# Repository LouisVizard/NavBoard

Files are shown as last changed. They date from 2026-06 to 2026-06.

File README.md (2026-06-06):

<div align="center">

# 🛰️ Navigation Board PCB

**A compact, 6-layer embedded navigation platform for real-time sensor fusion and wireless telemetry**







</div>

---

## 📌 Overview

The **Navigation Board** is a custom PCB designed as a dedicated navigation and state estimation platform. It integrates GNSS positioning, inertial sensing, and wireless communication onto a single, compact board — enabling real-time vehicle attitude estimation via a Kalman filter and live data streaming to a host computer for visualization.

> The hardware is complete and functional. Active development is now focused on firmware (EKF implementation) and the host-side Python visualization pipeline.

---

## 🖼️ Board Preview

| Isometric Top | Isometric Bottom |
|:---:|:---:|
| 3D Render Top | 3D Render Bottom |

<details>
<summary>📐 PCB Layout</summary>
<br>

PCB Layout

</details>

<details>
<summary>🔌 Full Schematic</summary>
<br>

Schematic

</details>

---

## ⚡ Specifications

| Parameter | Value |
|---|---|
| **MCU** | STM32F4CEU6 |
| **GNSS Receiver** | u-blox NEO-M9N |
| **IMU** | 9DOF — Accelerometer + Gyroscope + Magnetometer |
| **Wireless** | nRF24L01 (2.4 GHz RF) |
| **Power Input** | Single-cell LiPo + USB-C charging |
| **PCB Stackup** | 6-layer, impedance controlled |

---

## 🏗️ System Architecture

```
┌─────────────┐     ┌─────────────────────────┐     ┌──────────────────┐     ┌──────────────────┐
│  GNSS       │     │                         │     │                  │     │                  │
│  NEO-M9N    │────▶│     STM32F4CEU6         │────▶│  nRF24L01        │────▶│  Host PC         │
│  (UART)     │     │   Kalman Filter /        │     │  2.4 GHz RF Link │     │  Python Viz      │
├─────────────┤     │   Sensor Fusion          │     │                  │     │                  │
│  IMU 9DOF   │     │                         │     │                  │     │                  │
│  (SPI/I2C)  │────▶│                         │     │                  │     │                  │
└─────────────┘     └─────────────────────────┘     └──────────────────┘     └──────────────────┘
```

**Goal:** Fuse absolute positioning (GNSS) with high-rate inertial data (IMU) using an Extended Kalman Filter to estimate real-time orientation and motion, then stream state estimates wirelessly to a host computer for visualization.

---

## 🔧 Design Details

### Hardware Integration

The board centers around the **STM32F4** MCU, which interfaces with:
- **NEO-M9N** GNSS receiver over **UART** for global positioning
- **9DOF IMU** over **SPI/I2C** for high-rate motion sensing
- **nRF24L01** providing a low-latency **2.4 GHz RF link** to stream processed state estimates to an external computer

### Power System

Powered by a single-cell **LiPo battery** with onboard **USB-C charging** circuitry. Independent regulation stages supply stable rails for:
- RF front-end
- Digital logic
- Analog sensing paths

This architecture minimizes noise coupling into sensitive IMU measurements.

### PCB Stackup

A **6-layer stackup** was chosen to provide:
- Controlled impedance for RF and GNSS antenna traces
- Solid ground referencing across all layers
- Clean power distribution

Dedicated power and ground planes minimize EMI and improve signal integrity throughout.

---

## 📊 PCB Stackup Details

The full layer stackup with impedance targets and material specifications is documented in the design spreadsheet:

📄 **[View Stackup Spreadsheet (Google Sheets)](https://docs.google.com/spreadsheets/d/1y8UFBo5hvFj5DNxBOYgQXF0sVpvpMorS/preview)**

---

## 🗺️ Roadmap

The hardware platform is complete. Next steps are focused on firmware and software:

- [ ] Implement **Extended Kalman Filter (EKF)** for GNSS + IMU fusion on STM32F4
- [ ] Tune process and measurement noise covariance matrices
- [ ] Stream state estimates over nRF24L01 RF link
- [ ] Develop **Python visualization** for real-time attitude display
- [ ] Validate filter output against ground truth measurements

---

## 🛠️ Tech Stack

| Layer | Technology |
|---|---|
| **Hardware Design** | KiCad |
| **Firmware** | C (STM32 HAL / bare-metal) |
| **Host Software** | Python |
| **Comms Protocol** | nRF24L01 2.4 GHz |

---

## 👤 Author

**Luis Martinez**





---

<div align="center">
<sub>Built with KiCad · STM32 · u-blox · nRF24L01</sub>
</div>

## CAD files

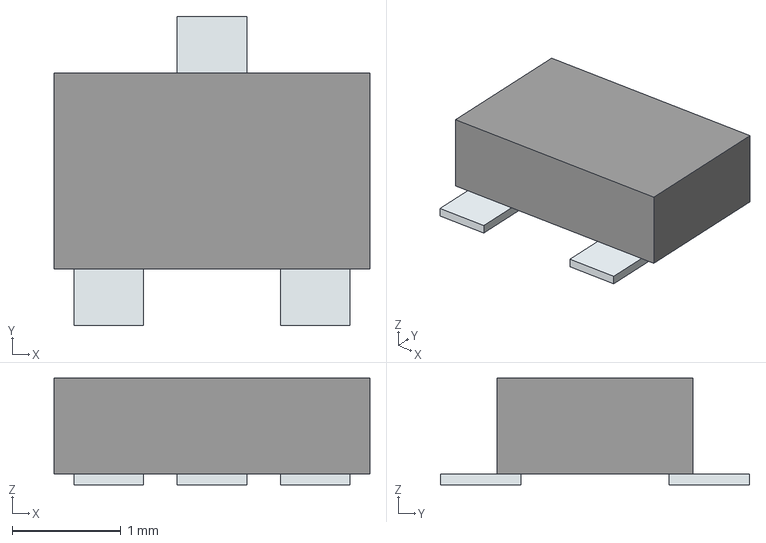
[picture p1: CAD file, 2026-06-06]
3D_Models/SSM3J372R,LF.stp
2.90 x 2.84 x 0.98 mm
Pins

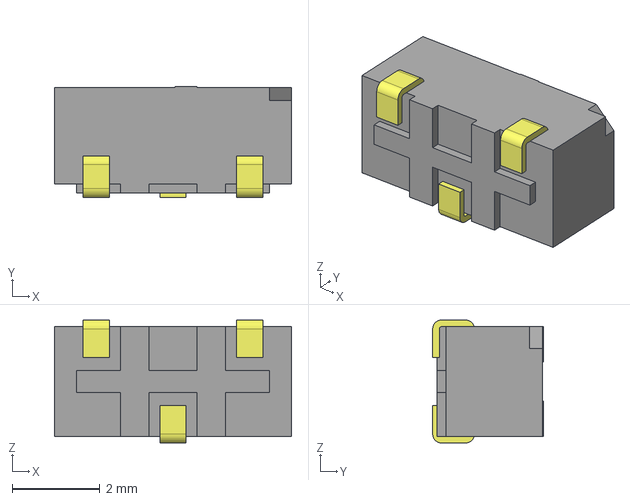
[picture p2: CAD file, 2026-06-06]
3D_Models/CJS-1200TA2.stp
5.40 x 2.52 x 2.80 mm
_CJS_c_11
_CJS Slider_s

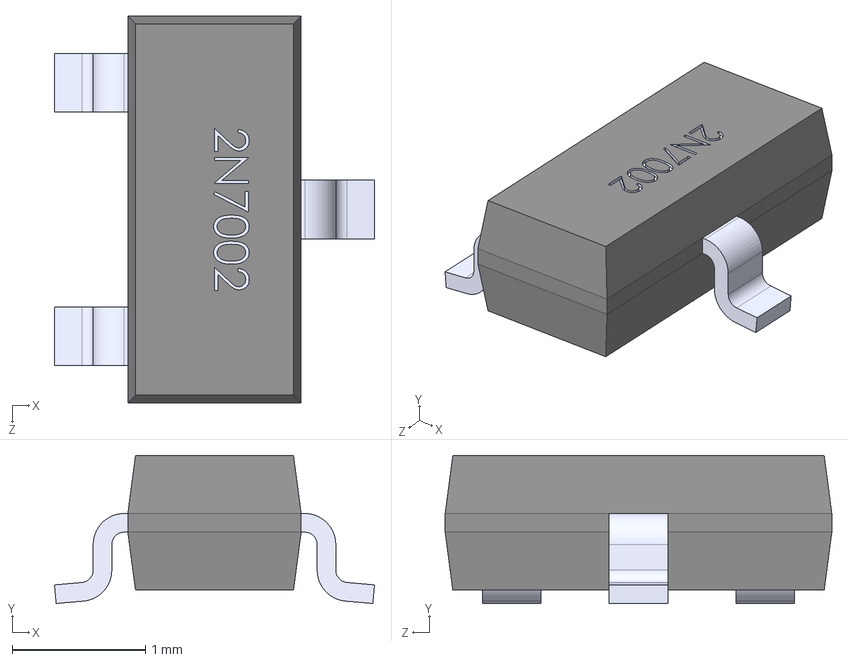
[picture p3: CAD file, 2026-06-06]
3D_Models/2N7002.stp
2.40 x 1.11 x 2.90 mm
2N7002_2
2N7002_3
2N7002_4
2N7002

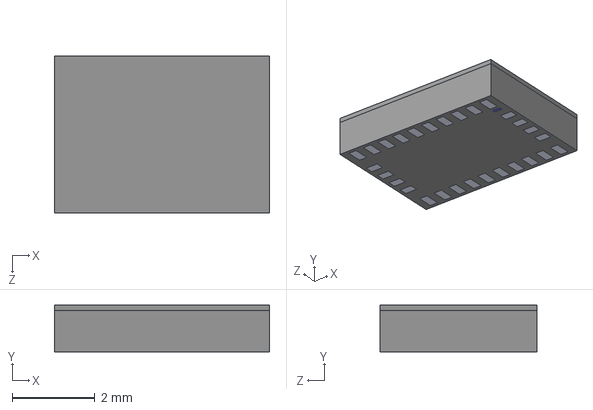
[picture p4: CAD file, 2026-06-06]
3D_Models/BNO086.stp
5.20 x 1.13 x 3.80 mm

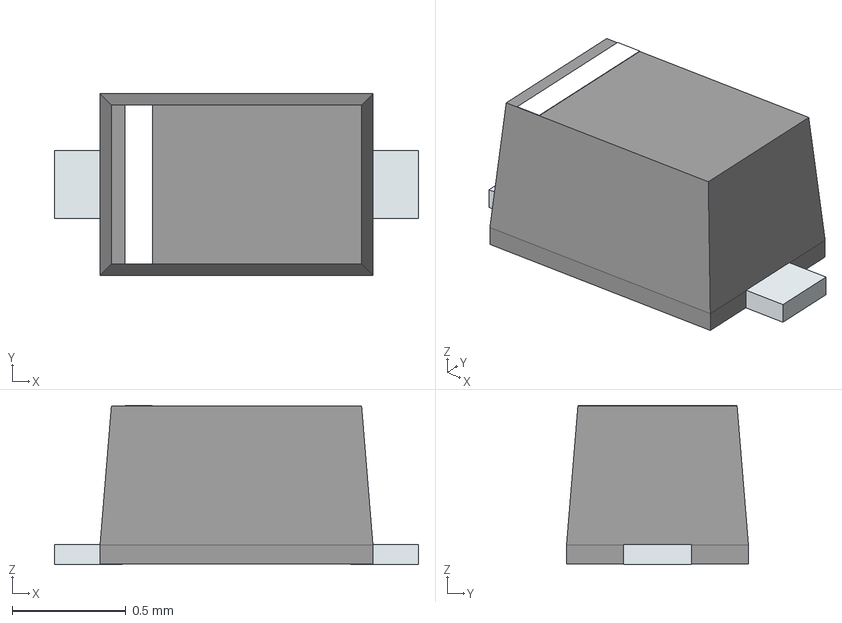
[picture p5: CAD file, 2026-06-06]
3D_Models/MM5Z10VT1G.stp
1.60 x 0.8 x 0.7 mm
PinKIdent
PinK
PinA

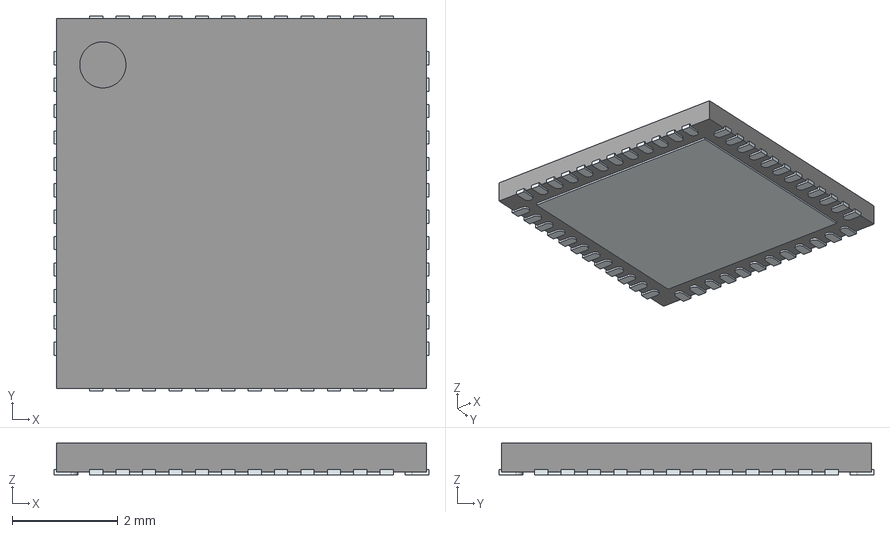
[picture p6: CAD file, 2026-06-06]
3D_Models/STM32F411CEU6.stp
7.10 x 7.10 x 0.6 mm
ThermalPin
PinsArrayLR
PinsArrayTB

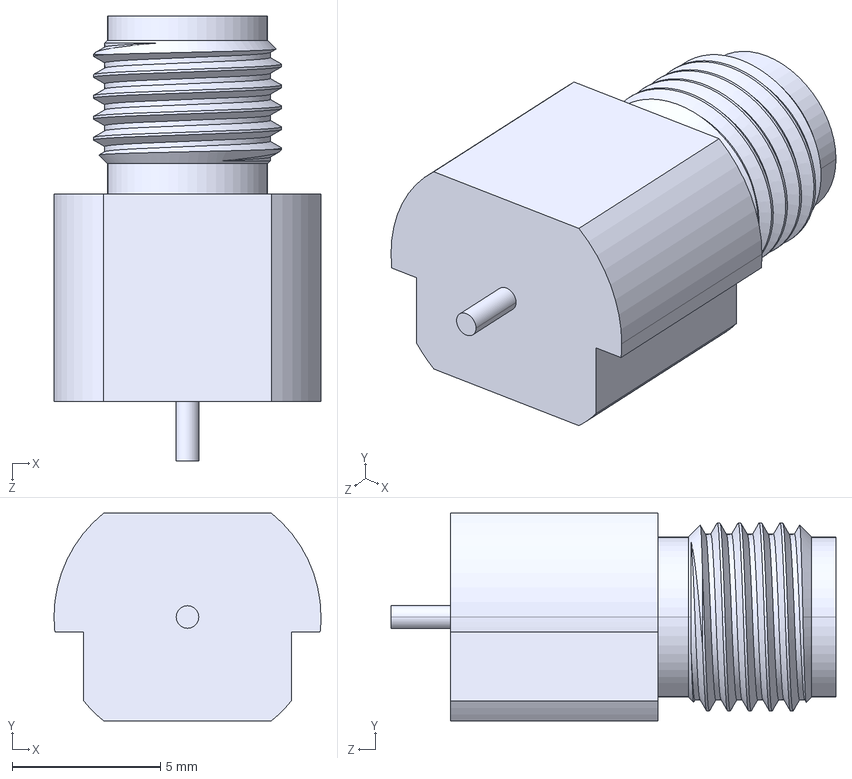
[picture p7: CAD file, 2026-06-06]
3D_Models/CONSMA024-G-T.stp
9.00 x 7.00 x 15.0 mm

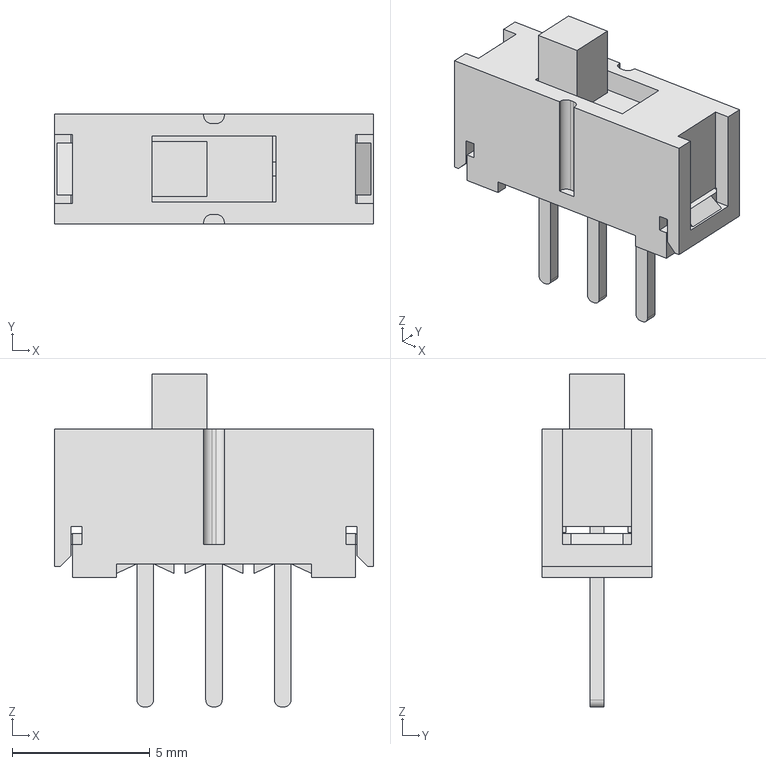
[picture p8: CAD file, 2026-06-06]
3D_Models/EG1218.stp
11.6 x 4.00 x 12.1 mm

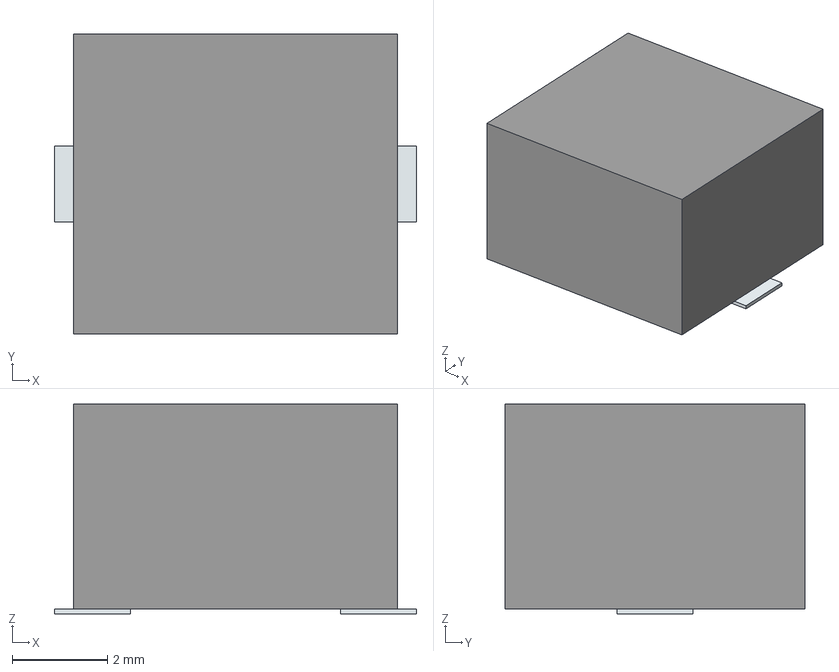
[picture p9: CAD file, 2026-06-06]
3D_Models/TS37-6368-41-R-400-SMT-TR.stp
7.60 x 6.30 x 4.40 mm
Pins

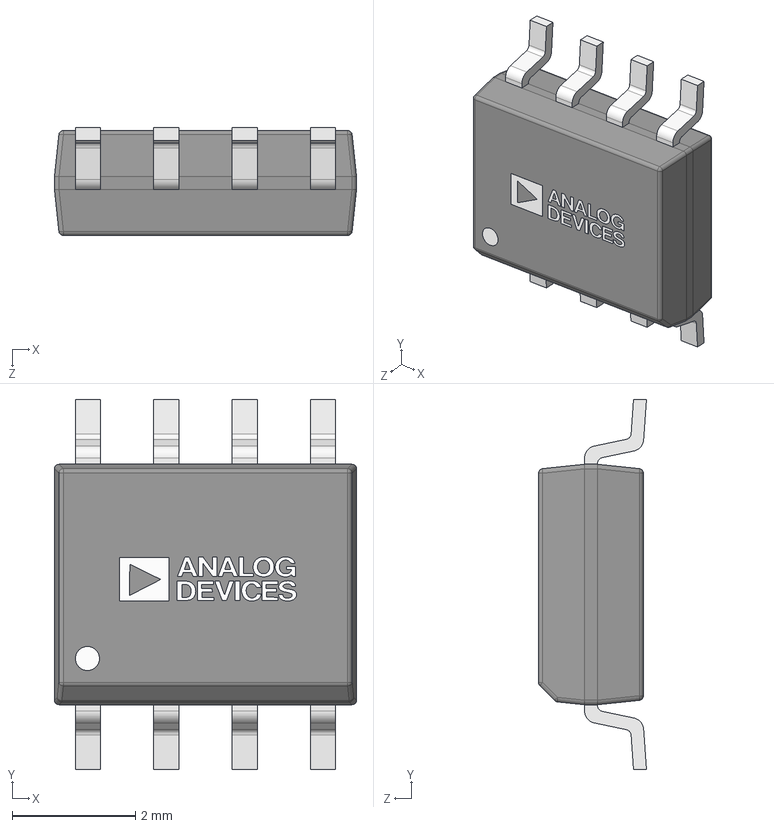
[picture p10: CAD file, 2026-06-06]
3D_Models/ADP7142ARDZ-3.3.stp
4.90 x 6.00 x 1.75 mm
ADP7104ARDZ-R7_+ Chamfer
Analog Devices logo_1mm-LAPTOP-NQA1DCQ3

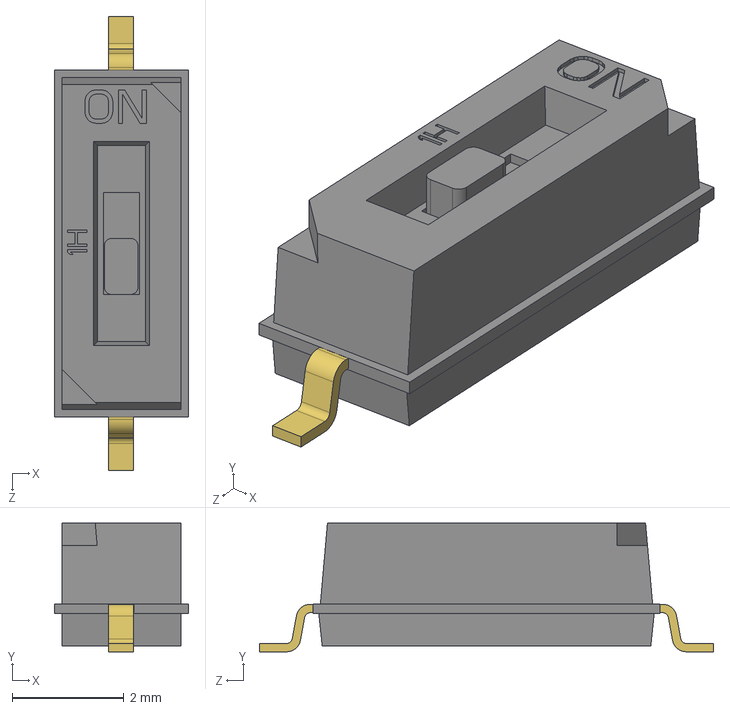
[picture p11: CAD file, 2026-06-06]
3D_Models/TDA01H0SB1R.stp
2.40 x 2.30 x 8.12 mm

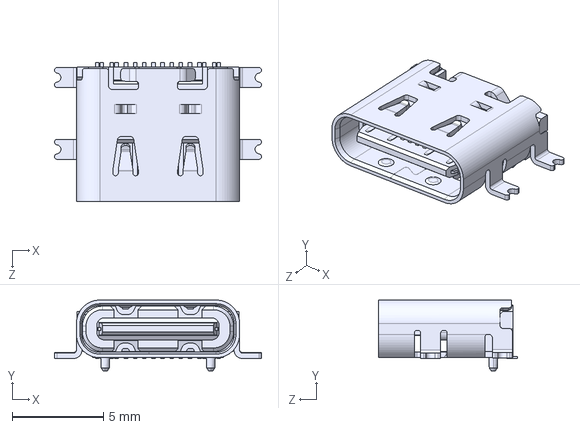
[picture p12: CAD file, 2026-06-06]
3D_Models/UJ20-C-H-G-SMT-5-P16-TR.stp
11.3 x 3.89 x 7.60 mm

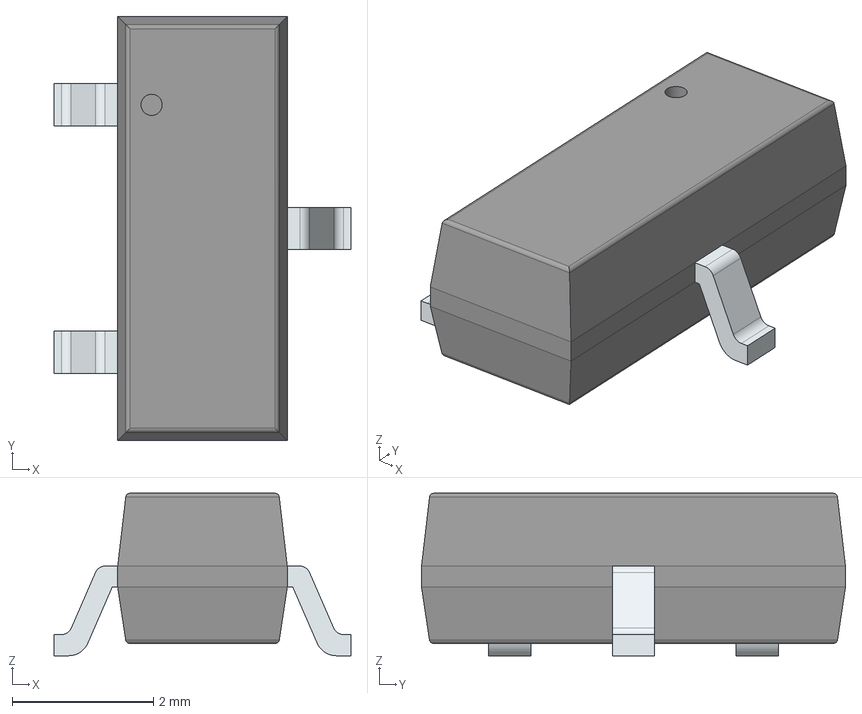
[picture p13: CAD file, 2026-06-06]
3D_Models/TDD01H0SB1R.stp
4.20 x 6.00 x 2.30 mm
PinsArrayL
FilletPinR

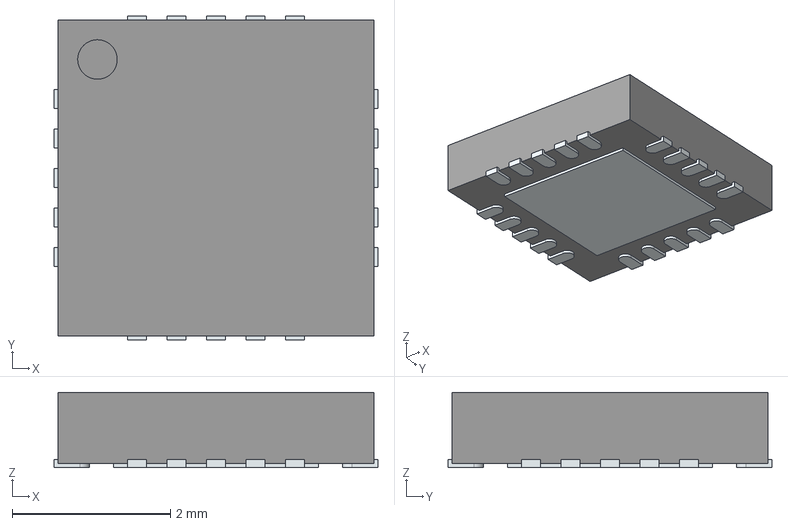
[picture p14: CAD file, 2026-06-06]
3D_Models/NRF24L01.stp
4.10 x 4.10 x 0.95 mm
ThermalPin
PinsArrayLR
PinsArrayTB

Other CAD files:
3D_Models/RFX2401C.stp
3D_Models/S2B-ZR_LF__SN_.stp
3D_Models/SM04B-XSRS-ETB_LF__SN_.stp
3D_Models/1825910-6.stp
3D_Models/2450LP14A0100001T.stp
3D_Models/ABS06-32.768KHZ-T.stp
3D_Models/CONSMA022-G.stp
3D_Models/MCP73833-FCI_MF.stp
3D_Models/NEO-M9N-00B.stp
3D_Models/PTS636SM43JSMTR_LFS.stp
3D_Models/PTS645VM39-2_LFS.stp
3D_Models/S4B-ZR-3.4_LF__SN_.stp
3D_Models/S4B-ZR-SM4A-TF_LF__SN_.stp
3D_Models/TLV75533PDBVR.stp
3D_Models/TPS2115ADRBR.stp
3D_Models/TPS61232DRCR.stp
3D_Models/XRCGB16M000FXN22R0.stp

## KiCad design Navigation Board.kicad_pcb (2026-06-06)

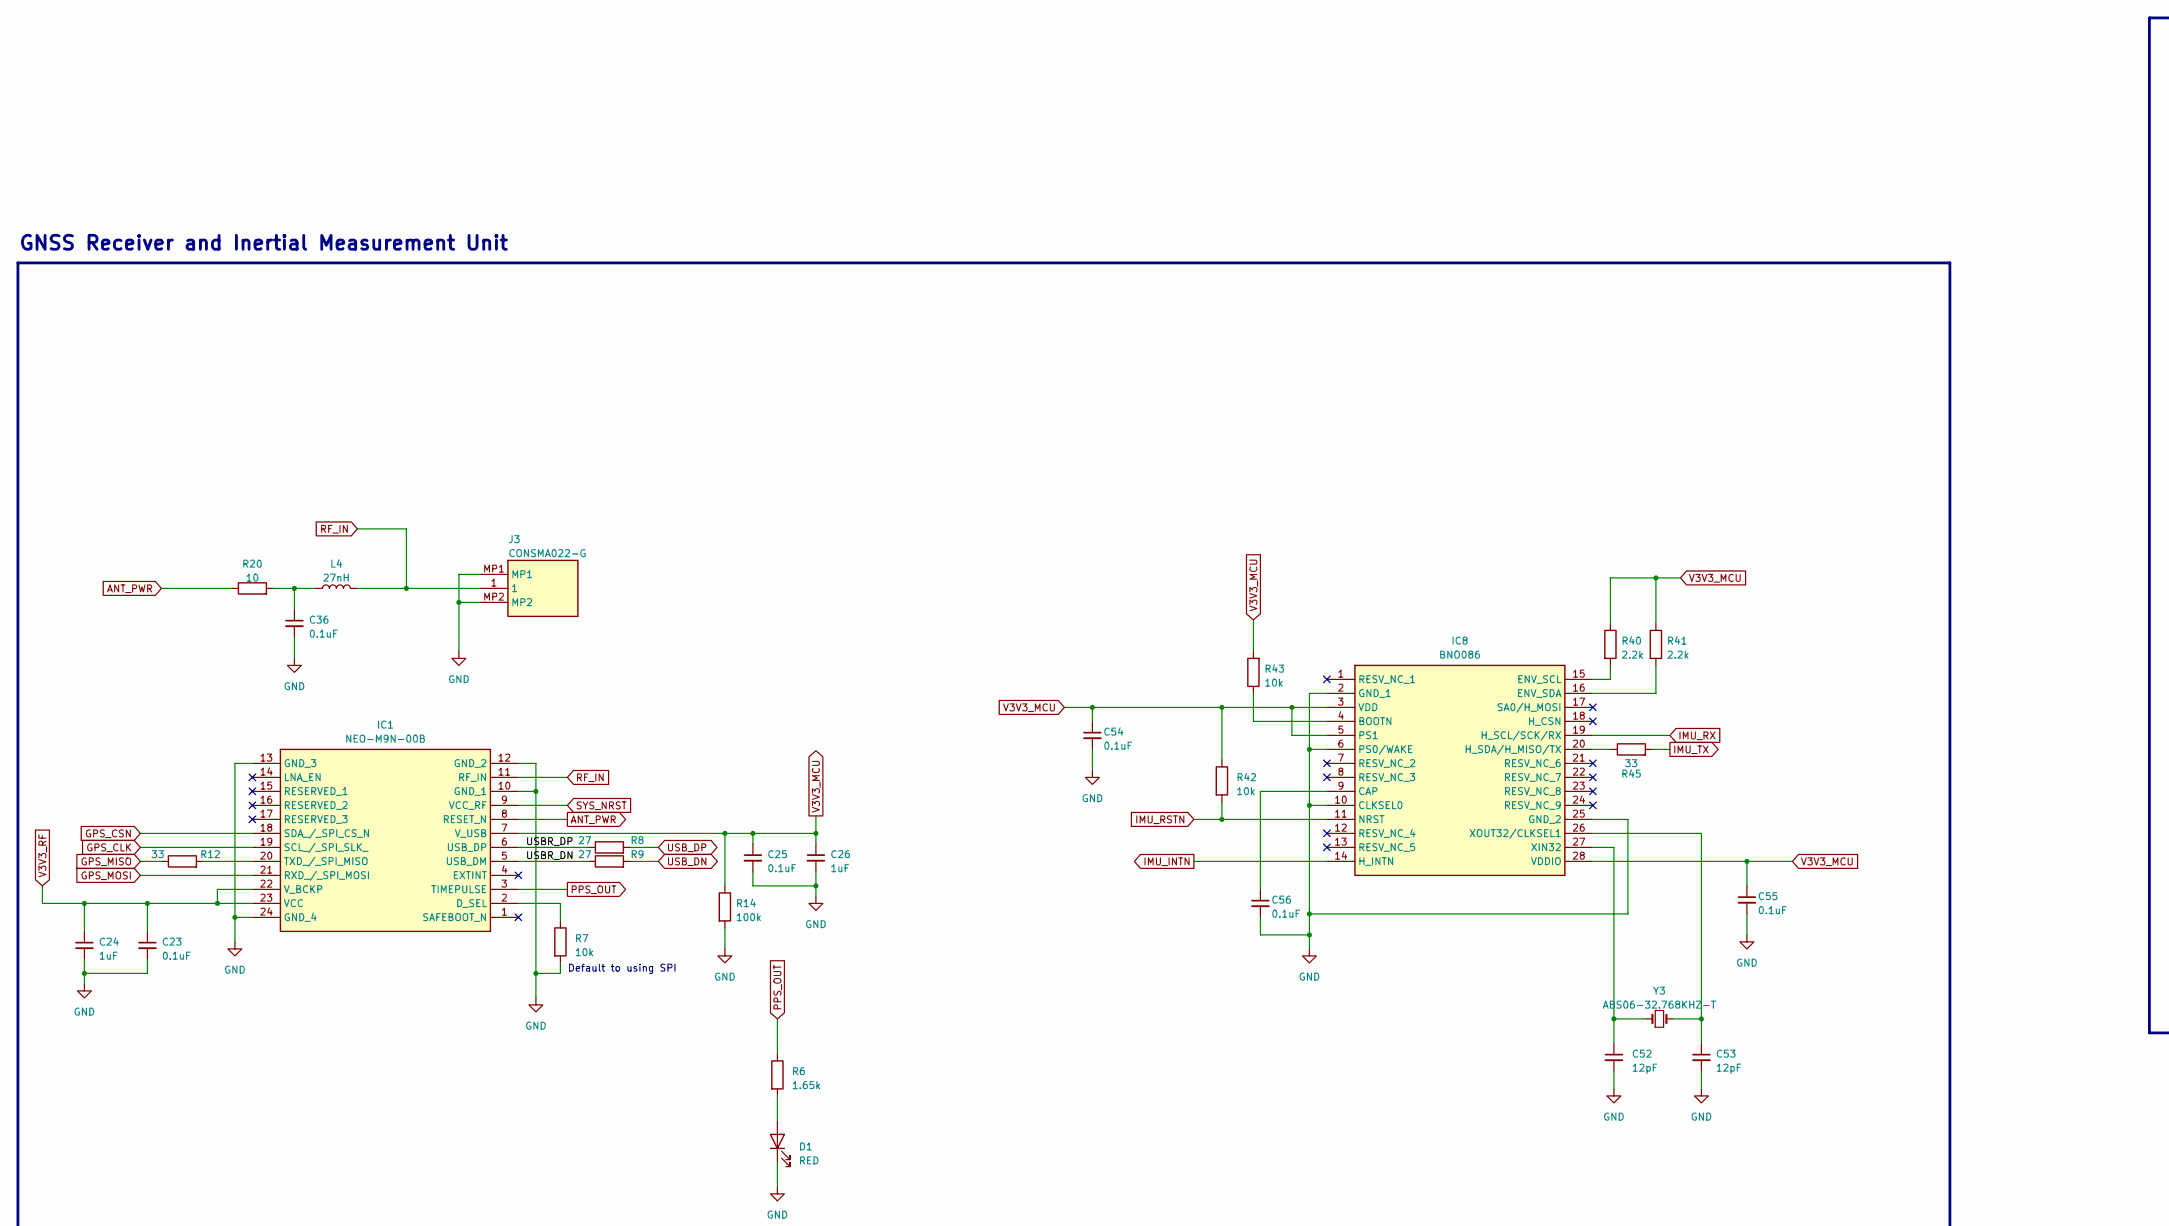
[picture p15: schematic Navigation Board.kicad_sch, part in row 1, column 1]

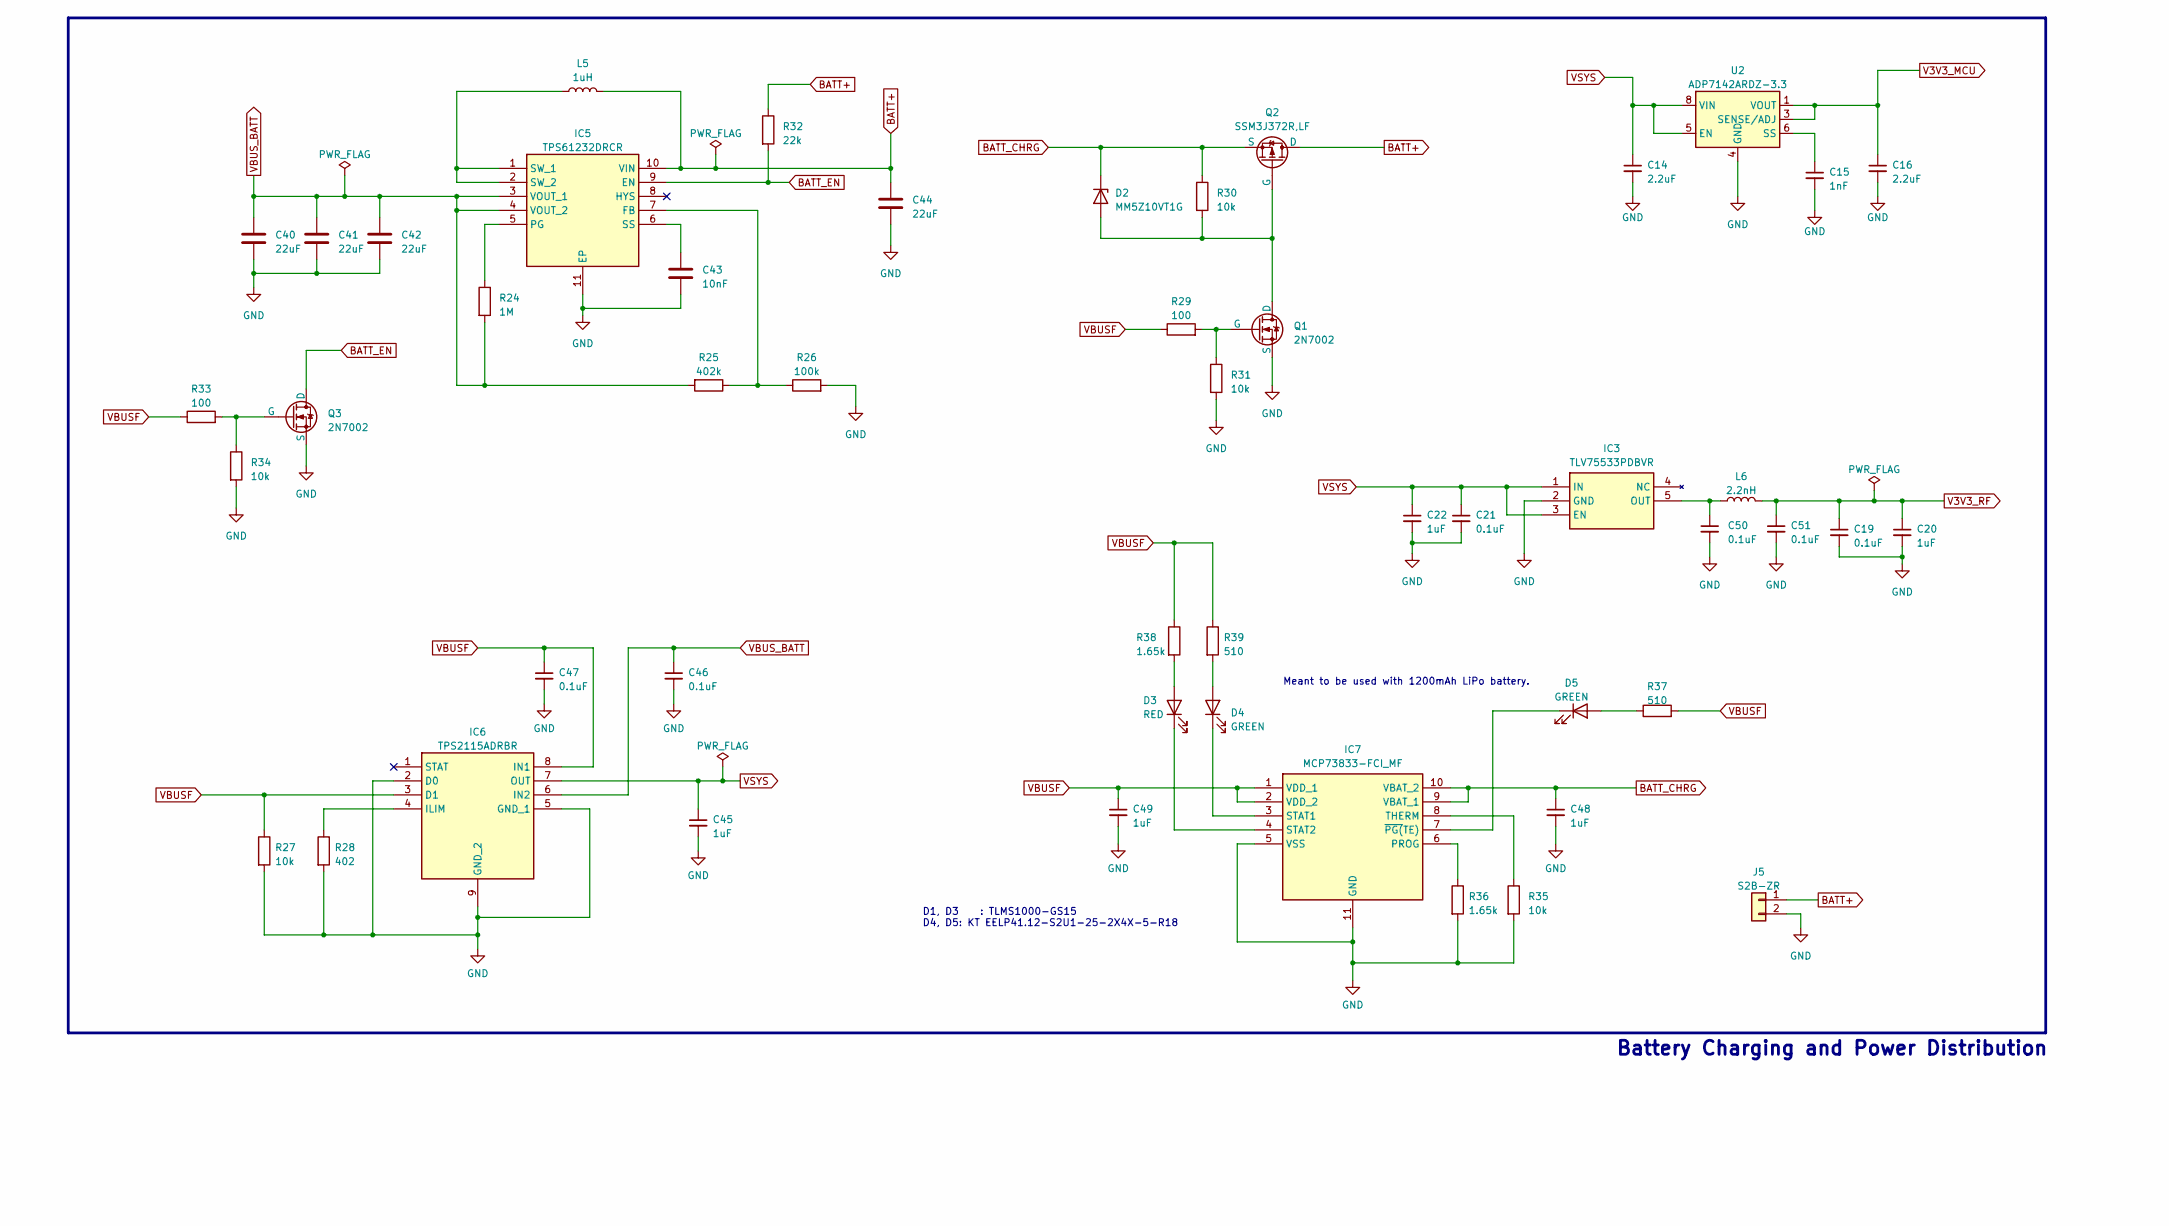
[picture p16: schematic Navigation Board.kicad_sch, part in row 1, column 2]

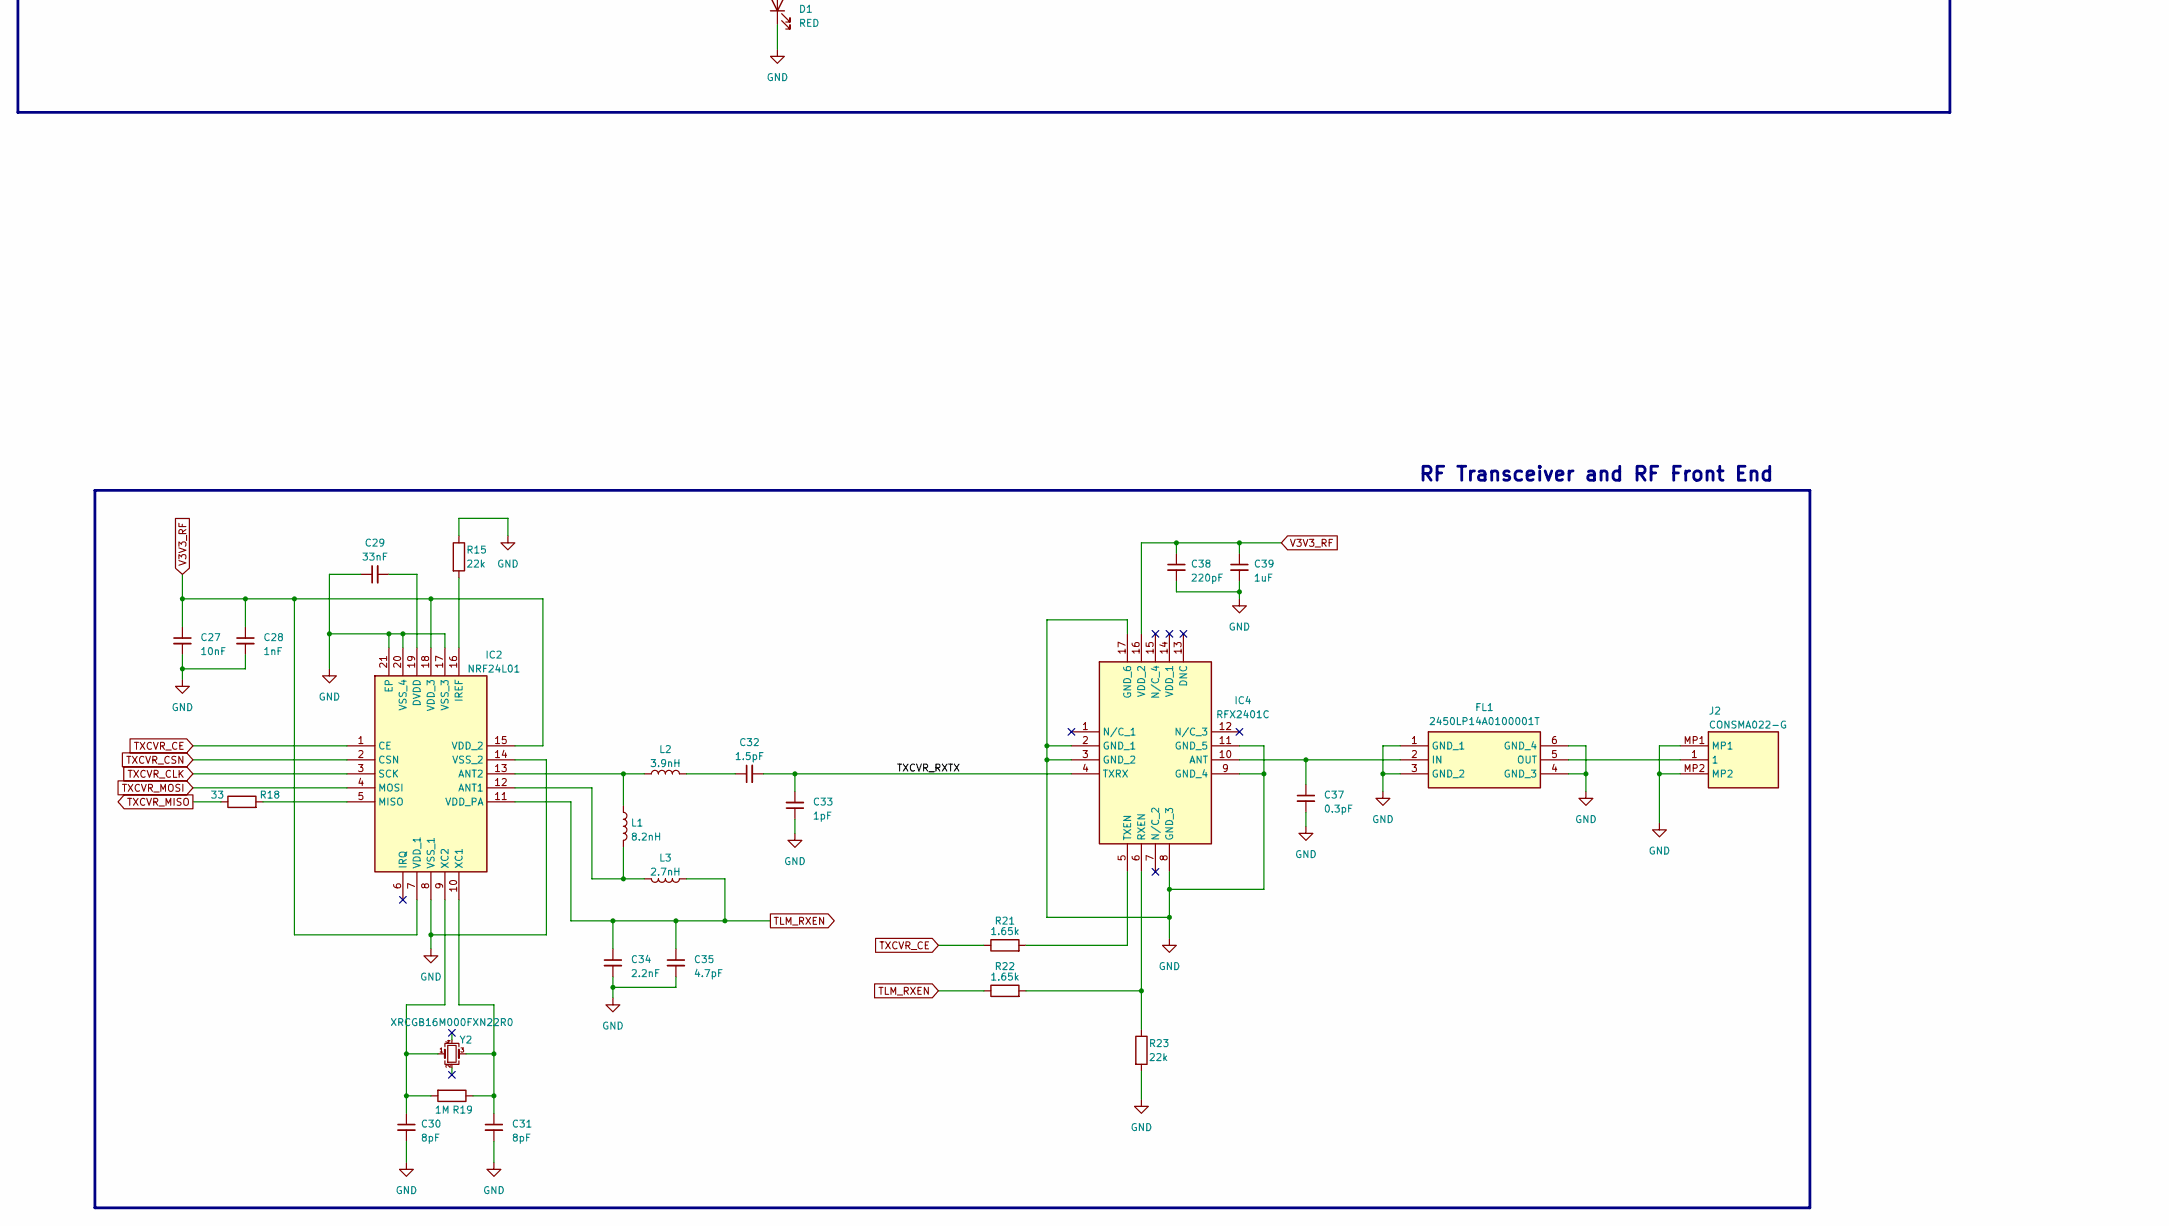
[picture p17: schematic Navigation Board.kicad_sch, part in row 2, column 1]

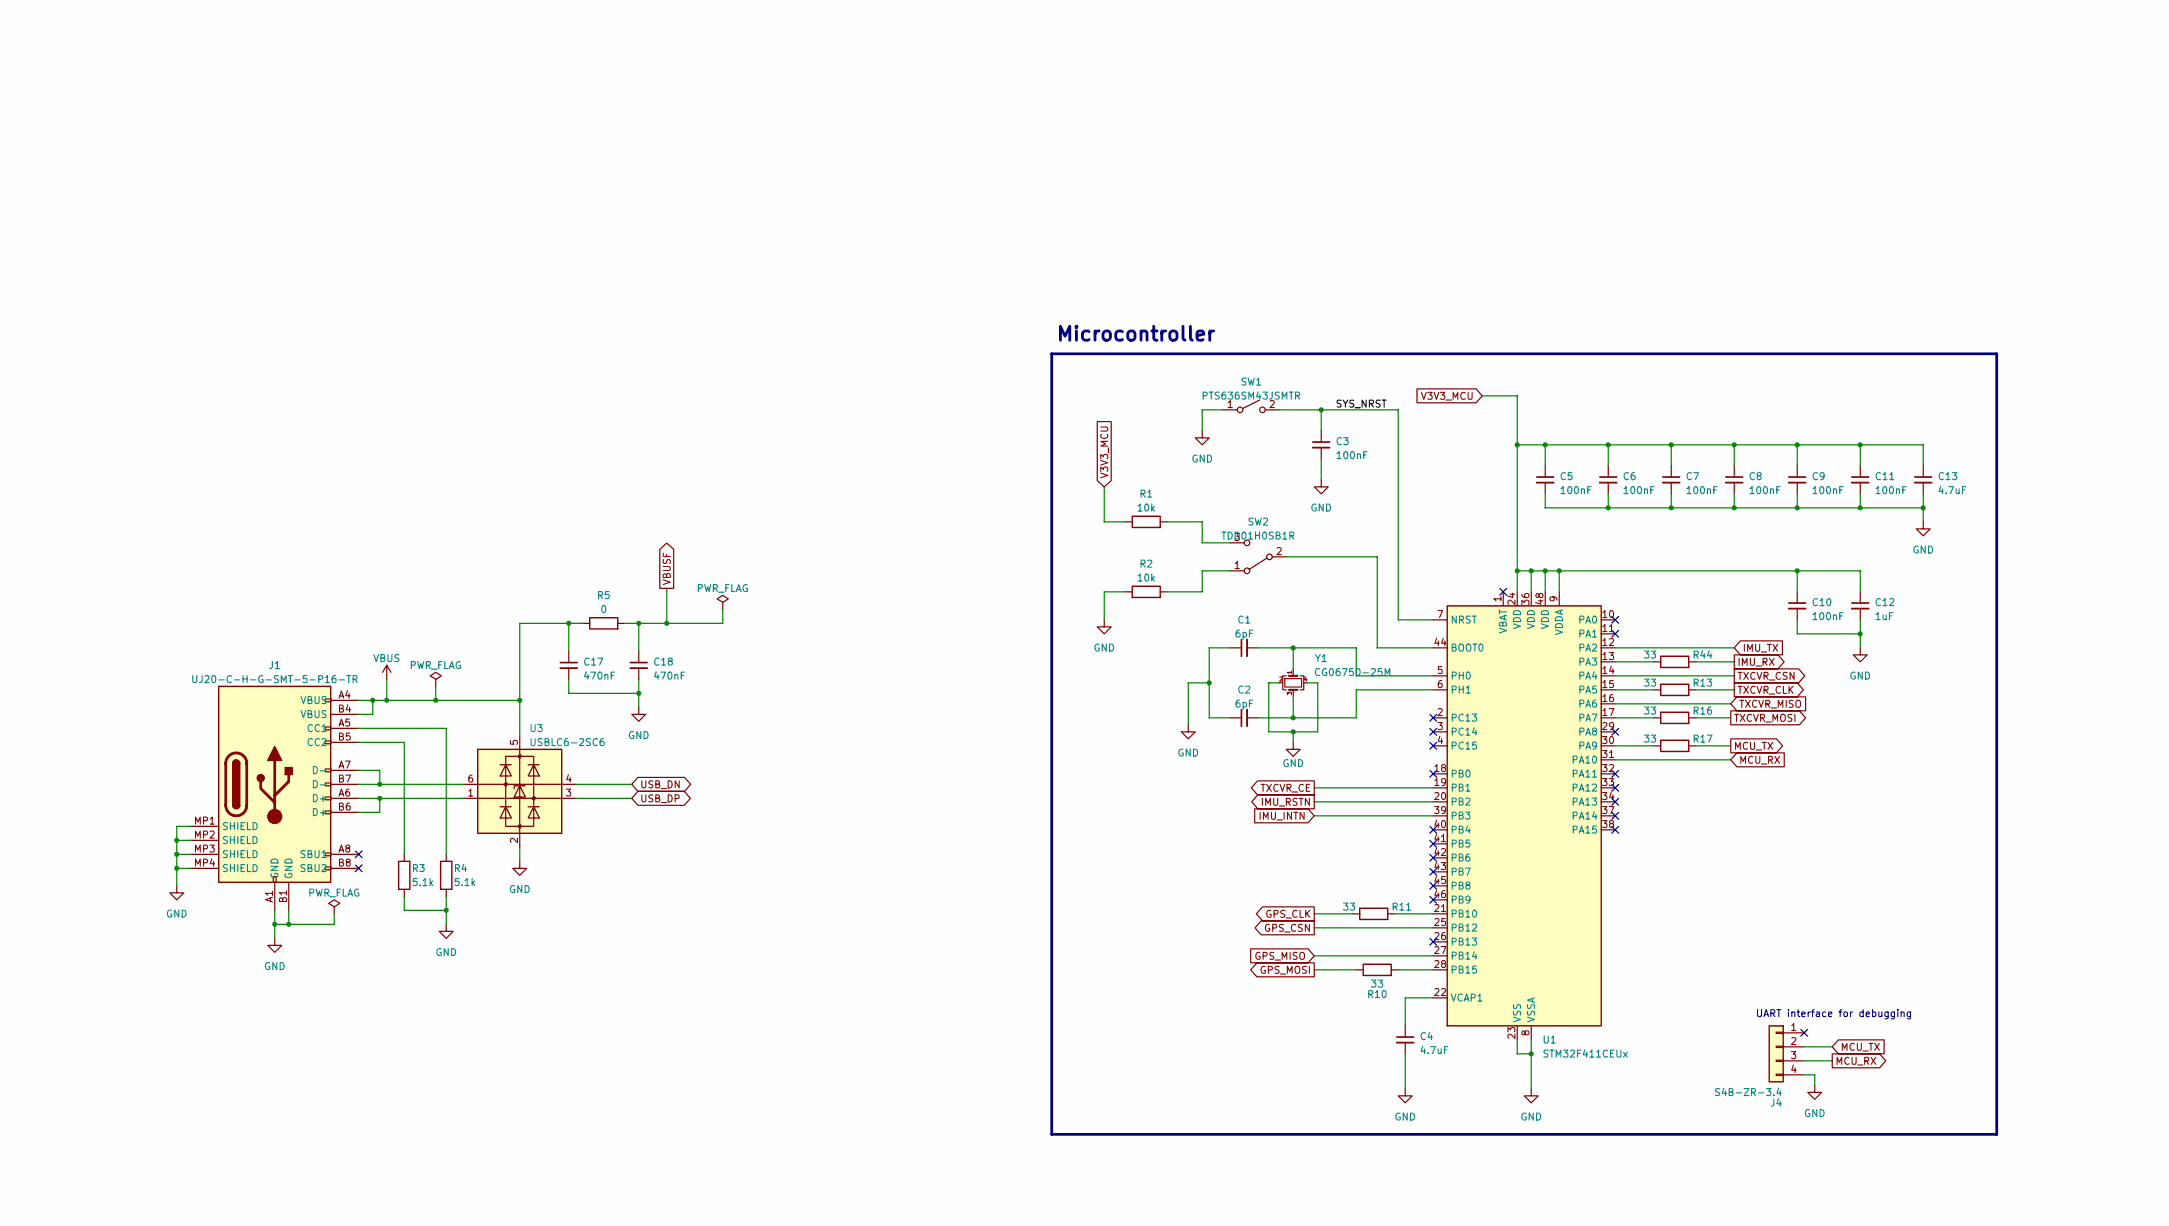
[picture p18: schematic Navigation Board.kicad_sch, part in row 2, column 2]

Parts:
C1, C2: 6pF; C_0603_1608Metric
C3, C5, C6, C7, C8, C9, C10, C11: 100nF; C_0603_1608Metric
C4, C13: 4.7uF; C_0805_2012Metric
C12, C20, C22, C24, C26, C39, C45, C48, C49: 1uF; C_0603_1608Metric
C14, C16: 2.2uF; C_0603_1608Metric
C15, C28: 1nF; C_0603_1608Metric
C17, C18: 470nF; C_0603_1608Metric
C19, C21, C23, C25, C36, C46, C47, C50, C51: 0.1uF; C_0603_1608Metric
C27: 10nF; C_0603_1608Metric
C29: 33nF; C_0402_1005Metric
C30, C31: 8pF; C_0402_1005Metric
C32: 1.5pF; C_0402_1005Metric
C33: 1pF; C_0402_1005Metric
C34: 2.2nF; C_0402_1005Metric
C35: 4.7pF; C_0402_1005Metric
C37: 0.3pF; C_0402_1005Metric
C38: 220pF; C_0603_1608Metric
C40, C41, C42, C44: 22uF; C_1206_3216Metric
C43: 10nF; C_0805_2012Metric
C52, C53: 12pF; C_0402_1005Metric
C54, C55, C56: 0.1uF; C_0402_1005Metric
D1, D3: RED; D_0603_1608Metric
D2: MM5Z10VT1G
D4, D5: GREEN; D_0603_1608Metric
FL1: 2450LP14A0100001T; Manufacturer_Part_Number 2450LP14A0100001T
IC1: NEO-M9N-00B; NEOM9N00B; Mouser Part Number 377-NEO-M9N-00B
IC2: NRF24L01; nRF24L01; Mouser Part Number 949-NRF24L01
IC3: TLV75533PDBVR; Mouser Part Number 595-TLV75533PDBVR
IC4: RFX2401C; Mouser Part Number 477-RFX2401C
IC5: TPS61232DRCR; Mouser Part Number 595-TPS61232DRCR
IC6: TPS2115ADRBR; Mouser Part Number 595-TPS2115ADRBR
IC7: MCP73833-FCI_MF; Mouser Part Number 579-MCP73833-FCI/MF
IC8: BNO086; Mouser Part Number 526-BNO086
J1: UJ20-C-H-G-SMT-5-P16-TR
J2, J3: CONSMA022-G; CONSMA022G; Mouser Part Number 712-CONSMA022-G
J4: S4B-ZR-3.4; S4BZR34LFSN
J5: S2B-ZR
L1: 8.2nH; L_0603_1608Metric
L2: 3.9nH; L_0603_1608Metric
L3: 2.7nH; L_0603_1608Metric
L4: 27nH; L_0603_1608Metric
L5: 1uH; L_Vishay_IHLP-1616
L6: 2.2nH; L_0402_1005Metric
Q1, Q3: 2N7002
Q2: SSM3J372R,LF; SSM3J372RLF
R1, R2, R7, R27, R30, R31, R34, R35, R42, R43: 10k; R_0603_1608Metric
R3, R4: 5.1k; R_0603_1608Metric
R5: 0; R_1210_3225Metric
R6, R21, R22, R36, R38: 1.65k; R_0603_1608Metric
R8, R9: 27; R_0603_1608Metric
R10, R11, R12, R13, R16, R17, R18, R44, R45: 33; R_0603_1608Metric
R14, R26: 100k; R_0805_2012Metric
R15, R23, R32: 22k; R_0805_2012Metric
R19, R24: 1M; R_0603_1608Metric
R20: 10; R_0805_2012Metric
R25: 402k; R_0603_1608Metric
R28: 402; R_0402_1005Metric
R29, R33: 100; R_0603_1608Metric
R37, R39: 510; R_0603_1608Metric
R40, R41: 2.2k; R_0603_1608Metric
SW1: PTS636SM43JSMTR; PTS636SM43JSMTRLFS
SW2: TDD01H0SB1R
U1: STM32F411CEUx; STM32F411CEU6
U2: ADP7142ARDZ-3.3
U3: USBLC6-2SC6; SOT-23-6
Y1: CG06750-25M
Y2: XRCGB16M000FXN22R0
Y3: ABS06-32.768KHZ-T

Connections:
/TXCVR_RXTX: C32.2, C33.2, IC4.4 (TXRX)
/USBR_DN: IC1.5 (USB_DM), R9.1
/USBR_DP: IC1.6 (USB_DP), R8.1
ANT_PWR: IC1.8 (RESET_N), R20.1
BATT+: C44.1, IC5.10 (VIN), J5.1, L5.2, Q2.1 (D), R32.1
BATT_CHRG: C48.1, D2.1 (K), IC7.9 (VBAT_1), IC7.10 (VBAT_2), Q2.3 (S), R30.1
BATT_EN: IC5.9 (EN), Q3.1 (D), R32.2
GND: C1.1, C2.1, C3.2, C4.2, C5.2, C6.2, C7.2, C8.2, C9.2, C10.2, C11.2, C12.2, C13.2, C14.2, C15.2, C16.2, C17.2, C18.2, C19.2, C20.2, C21.2, C22.2, C23.2, C24.2, C25.2, C26.2, C27.2, C28.2, C29.1, C30.2, C31.2, C33.1, C34.2, C35.2, C36.2, C37.2, C38.2, C39.2, C40.2, C41.2, C42.2, C43.2, C44.2, C45.2, C46.2, C47.2, C48.2, C49.2, C50.2, C51.2, C52.2, C53.2, C54.2, C55.2, C56.2, D1.1 (K), FL1.1 (GND_1), FL1.3 (GND_2), FL1.4 (GND_3), FL1.6 (GND_4), IC1.10 (GND_1), IC1.12 (GND_2), IC1.13 (GND_3), IC1.24 (GND_4), IC2.8 (VSS_1), IC2.14 (VSS_2), IC2.17 (VSS_3), IC2.20 (VSS_4), IC2.21 (EP), IC3.2 (GND), IC4.2 (GND_1), IC4.3 (GND_2), IC4.8 (GND_3), IC4.9 (GND_4), IC4.11 (GND_5), IC4.17 (GND_6), IC5.11 (EP), IC6.2 (D0), IC6.5 (GND_1), IC6.9 (GND_2), IC7.5 (VSS), IC7.11 (GND), IC8.2 (GND_1), IC8.6 (PS0/WAKE), IC8.10 (CLKSEL0), IC8.25 (GND_2), J1.A1 (GND), J1.B1 (GND), J1.MP1 (SHIELD), J1.MP2 (SHIELD), J1.MP3 (SHIELD), J1.MP4 (SHIELD), J2.MP1, J2.MP2, J3.MP1, J3.MP2, J4.4, J5.2, Q1.3 (S), Q3.3 (S), R2.1, R3.2, R4.2, R7.2, R14.2, R15.1, R23.2, R26.2, R27.2, R28.2, R31.2, R34.2, R35.2, R36.2, SW1.1 (A), U1.8 (VSSA), U1.23 (VSS), U1.35 (VSS), U1.47 (VSS), U1.49 (VSS), U2.4 (GND), U2.9 (GND), U3.2 (GND), Y1.2, Y1.4
GPS_CLK: IC1.19 (SCL_/_SPI_SLK_), R11.1
GPS_CSN: IC1.18 (SDA_/_SPI_CS_N), U1.25 (PB12)
GPS_MISO: R12.1, U1.27 (PB14)
GPS_MOSI: IC1.21 (RXD_/_SPI_MOSI), R10.1
IMU_INTN: IC8.14 (H_INTN), U1.39 (PB3)
IMU_RSTN: IC8.11 (NRST), R42.2, U1.20 (PB2)
IMU_RX: IC8.19 (H_SCL/SCK/RX), R44.2
IMU_TX: R45.2, U1.12 (PA2)
MCU_RX: J4.3, U1.31 (PA10)
MCU_TX: J4.2, R17.2
unnamed: C32.1, L2.2
unnamed: C36.1, L4.1, R20.2
unnamed: D1.2 (A), R6.2
unnamed: D2.2 (A), Q1.1 (D), Q2.2 (G), R30.2
unnamed: D3.2 (A), R38.2
unnamed: D3.1 (K), IC7.4 (STAT2)
unnamed: D4.2 (A), R39.2
unnamed: D4.1 (K), IC7.3 (STAT1)
unnamed: D5.2 (A), R37.1
unnamed: D5.1 (K), IC7.7 (~PG(TE))
unnamed: C37.1, FL1.2 (IN), IC4.10 (ANT)
unnamed: FL1.5 (OUT), J2.1
unnamed: IC1.2 (D_SEL), R7.1
unnamed: IC1.20 (TXD_/_SPI_MISO), R12.2
unnamed: IC2.12 (ANT1), L1.2, L3.2
unnamed: IC2.13 (ANT2), L1.1, L2.1
unnamed: C29.2, IC2.19 (DVDD)
unnamed: IC2.16 (IREF), R15.2
unnamed: IC2.5 (MISO), R18.2
unnamed: C31.1, IC2.10 (XC1), R19.1, Y2.3
unnamed: C30.1, IC2.9 (XC2), R19.2, Y2.1
unnamed: C50.1, IC3.5 (OUT), L6.1
unnamed: IC4.6 (RXEN), R22.2, R23.1
unnamed: IC4.5 (TXEN), R21.2
unnamed: IC5.7 (FB), R25.1, R26.1
unnamed: IC5.5 (PG), R24.1
unnamed: C43.1, IC5.6 (SS)
unnamed: IC5.1 (SW_1), IC5.2 (SW_2), L5.1
unnamed: IC6.4 (ILIM), R28.1
unnamed: IC7.6 (PROG), R36.1
unnamed: IC7.8 (THERM), R35.1
unnamed: IC8.4 (BOOTN), R43.1
unnamed: C56.1, IC8.9 (CAP)
unnamed: IC8.15 (ENV_SCL), R40.2
unnamed: IC8.16 (ENV_SDA), R41.2
unnamed: IC8.20 (H_SDA/H_MISO/TX), R45.1
unnamed: C52.1, IC8.27 (XIN32), Y3.1
unnamed: C53.1, IC8.26 (XOUT32/CLKSEL1), Y3.2
unnamed: J1.A5 (CC1), R4.1
unnamed: J1.B5 (CC2), R3.1
unnamed: J1.A6 (D+), J1.B6 (D+), U3.1 (I/O1)
unnamed: J1.A7 (D-), J1.B7 (D-), U3.6 (I/O1)
unnamed: Q1.2 (G), R29.2, R31.1
unnamed: Q3.2 (G), R33.2, R34.1
unnamed: R2.2, SW2.1 (A)
unnamed: SW2.2 (B), U1.44 (BOOT0)
unnamed: R1.2, SW2.3 (C)
unnamed: R44.1, U1.13 (PA3)
unnamed: R13.1, U1.15 (PA5)
unnamed: R16.1, U1.17 (PA7)
unnamed: R17.1, U1.30 (PA9)
unnamed: R11.2, U1.21 (PB10)
unnamed: R10.2, U1.28 (PB15)
unnamed: C1.2, U1.5 (PH0), Y1.1
unnamed: C2.2, U1.6 (PH1), Y1.3
unnamed: C4.1, U1.22 (VCAP1)
unnamed: C15.1, U2.6 (SS)
PPS_OUT: IC1.3 (TIMEPULSE), R6.1
RF_IN: IC1.11 (RF_IN), J3.1, L4.2
SYS_NRST: C3.1, IC1.9 (VCC_RF), SW1.2 (B), U1.7 (NRST)
TLM_RXEN: C34.1, C35.1, IC2.11 (VDD_PA), L3.1, R22.1
TXCVR_CE: IC2.1 (CE), R21.1, U1.19 (PB1)
TXCVR_CLK: IC2.3 (SCK), R13.2
TXCVR_CSN: IC2.2 (CSN), U1.14 (PA4)
TXCVR_MISO: R18.1, U1.16 (PA6)
TXCVR_MOSI: IC2.4 (MOSI), R16.2
USB_DN: R9.2, U3.4 (I/O2)
USB_DP: R8.2, U3.3 (I/O2)
V3V3_MCU: C5.1, C6.1, C7.1, C8.1, C9.1, C10.1, C11.1, C12.1, C13.1, C16.1, C25.1, C26.1, C54.1, C55.1, IC1.7 (V_USB), IC8.3 (VDD), IC8.5 (PS1), IC8.28 (VDDIO), R1.1, R14.1, R40.1, R41.1, R42.1, R43.2, U1.9 (VDDA), U1.24 (VDD), U1.36 (VDD), U1.48 (VDD), U2.1 (VOUT), U2.2 (VOUT), U2.3 (SENSE/ADJ)
V3V3_RF: C19.1, C20.1, C23.1, C24.1, C27.1, C28.1, C38.1, C39.1, C51.1, IC1.22 (V_BCKP), IC1.23 (VCC), IC2.7 (VDD_1), IC2.15 (VDD_2), IC2.18 (VDD_3), IC4.16 (VDD_2), L6.2
VBUS: C17.1, J1.A4 (VBUS), J1.B4 (VBUS), R5.1, U3.5 (VBUS)
VBUSF: C18.1, C47.1, C49.1, IC6.3 (D1), IC6.8 (IN1), IC7.1 (VDD_1), IC7.2 (VDD_2), R5.2, R27.1, R29.1, R33.1, R37.2, R38.1, R39.1
VBUS_BATT: C40.1, C41.1, C42.1, C46.1, IC5.3 (VOUT_1), IC5.4 (VOUT_2), IC6.6 (IN2), R24.2, R25.2
VSYS: C14.1, C21.1, C22.1, C45.1, IC3.1 (IN), IC3.3 (EN), IC6.7 (OUT), U2.5 (EN), U2.7 (VIN), U2.8 (VIN)

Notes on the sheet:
D1, D3 : TLMS1000-GS15 D4, D5: KT EELP41.12-S2U1-25-2X4X-5-R18
UART interface for debugging
Default to using SPI
Microcontroller
Battery Charging and Power Distribution
Meant to be used with 1200mAh LiPo battery.
GNSS Receiver and Inertial Measurement Unit
RF Transceiver and RF Front End

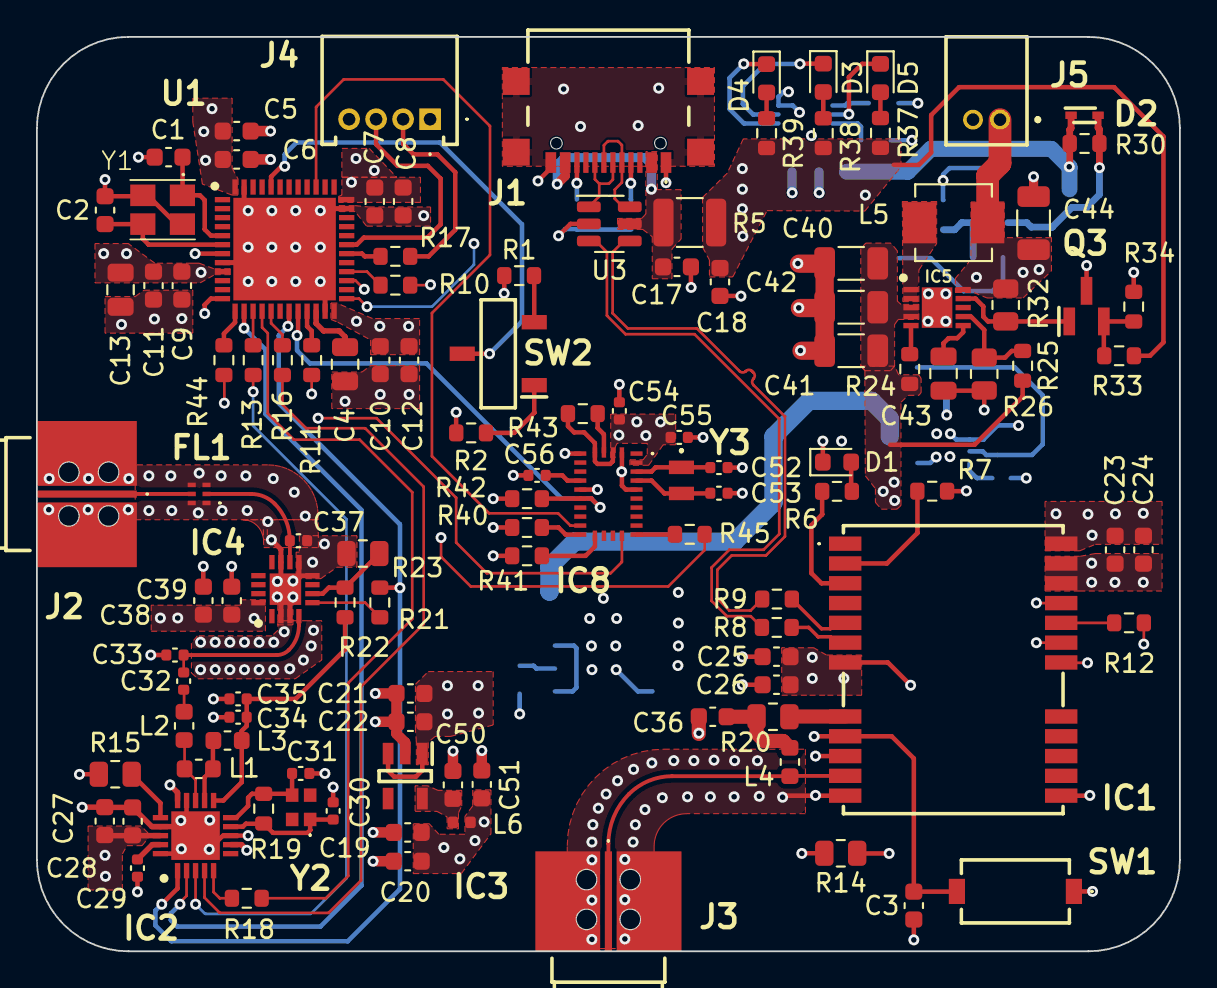
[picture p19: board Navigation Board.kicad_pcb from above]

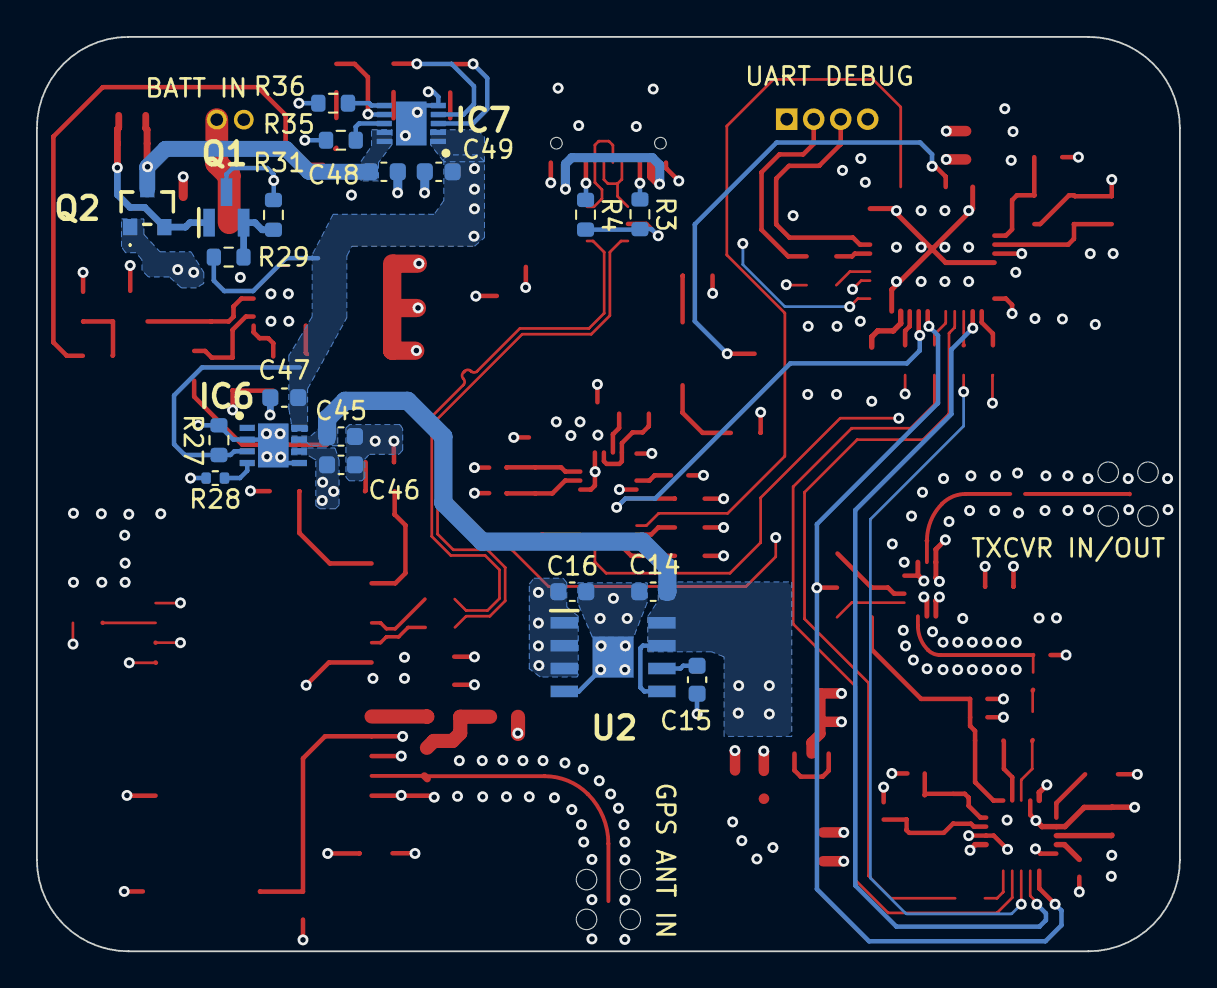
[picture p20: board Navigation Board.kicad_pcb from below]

Board: 6 copper layers, 63.5 x 50.8 mm, 137 parts (21 on the bottom side), 92 nets.

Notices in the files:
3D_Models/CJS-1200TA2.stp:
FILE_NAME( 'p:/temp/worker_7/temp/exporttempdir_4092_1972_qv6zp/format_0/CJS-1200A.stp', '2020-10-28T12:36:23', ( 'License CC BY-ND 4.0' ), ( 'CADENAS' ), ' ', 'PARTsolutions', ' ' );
